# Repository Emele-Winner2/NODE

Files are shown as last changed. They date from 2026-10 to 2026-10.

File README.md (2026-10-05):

# NODE IO BOARD

The **NODE IO BOARD** is an embedded hardware node featuring an **ESP32-C3** microcontroller, onboard environmental and motion sensors, USB-C power/data delivery, and external micro-SD card storage. It serves as a compact, all-in-one sensor node designed for IoT applications, environmental monitoring, and motion tracking.

---

## Technical Specifications

### 1. Main Controller

* **MCU:** ESP32-C3-MINI-1 / ESP32-C3-MINI-2 module (RISC-V single-core processor).

* **Auto-Flash/Reset Circuitry:** Dual NPN transistor circuit (DTR/RTS) for automatic bootloader entry and flashing over USB.

* **Tactile Switches:** Dedicated `RESET` and `BOOT` push buttons.

### 2. Power Supply

* **Power Input:** USB Type-C Receptacle (USB 2.0 interface) or external 5V input header (`J2`).

* **ESD Protection:** Dedicated ESD protection diodes (`ESD9B5.0ST5G`) across VBUS, D+, and D- lines.

* **Voltage Regulation:** Onboard **LD1117S33TR** LDO regulator stepping down 5V (VBUS) to 3.3V for MCU and sensor power rails.

### 3. USB to UART Bridge

* **Bridge IC:** **CP2102N** (QFN-28) USB-to-UART bridge controller.

* Communicates directly with the ESP32-C3 via `U0RXD` and `U0TXD` pins.

### 4. Onboard Sensors & Peripherals

* **Environmental Sensor:** **BME688** gas, temperature, pressure, and humidity sensor connected over I²C (`SCL`, `SDA`).

* **Inertial Measurement Unit (IMU):** **BMI323** 6-axis IMU connected via I²C (`SCL`, `SDA`) with dedicated interrupt lines (`BMI_INT1`, `BMI_INT2`).

* **MicroSD Card Slot:** SPI-driven SD card slot (`MEM2067`) connected via SPI lines (`SPI_CLK`, `MOSI`, `MISO`, `SPI_CS`) for local data logging.

---

## Block Diagram Overview

```text
               +-----------------------+
               |  USB-C / 5V Header    |
               +-----------+-----------+
                           |
            +--------------+--------------+
            |                             |
    +-------v-------+             +-------v-------+
    | 3.3V LDO      |             | CP2102N USB-  |
    | (LD1117S33)   |             | to-UART Bridge|
    +-------+-------+             +-------+-------+
            |                             |
            +--------------+--------------+
                           |
                 +---------v---------+
                 |    ESP32-C3       |
                 |  Microcontroller  |
                 +----+----+----+----+
                      |    |    |
       +--------------+    |    +---------------+
       | I2C               | SPI                | Interrupts / Controls
+------v-------+    +------v-------+    +-------v------+
|   BME688     |    |  MicroSD     |    | Boot & Reset |
| Env Sensor   |    | Card Slot    |    |   Buttons    |
+--------------+    +--------------+    +--------------+
|   BMI323     |
|  6-Axis IMU  |
+--------------+

```

## Project Design Files

This hardware project was designed in **KiCad 10.0**:

* `NODE IO BOARD.kicad_sch` — Schematic source file

* Hardware revision: **Rev 1.0**

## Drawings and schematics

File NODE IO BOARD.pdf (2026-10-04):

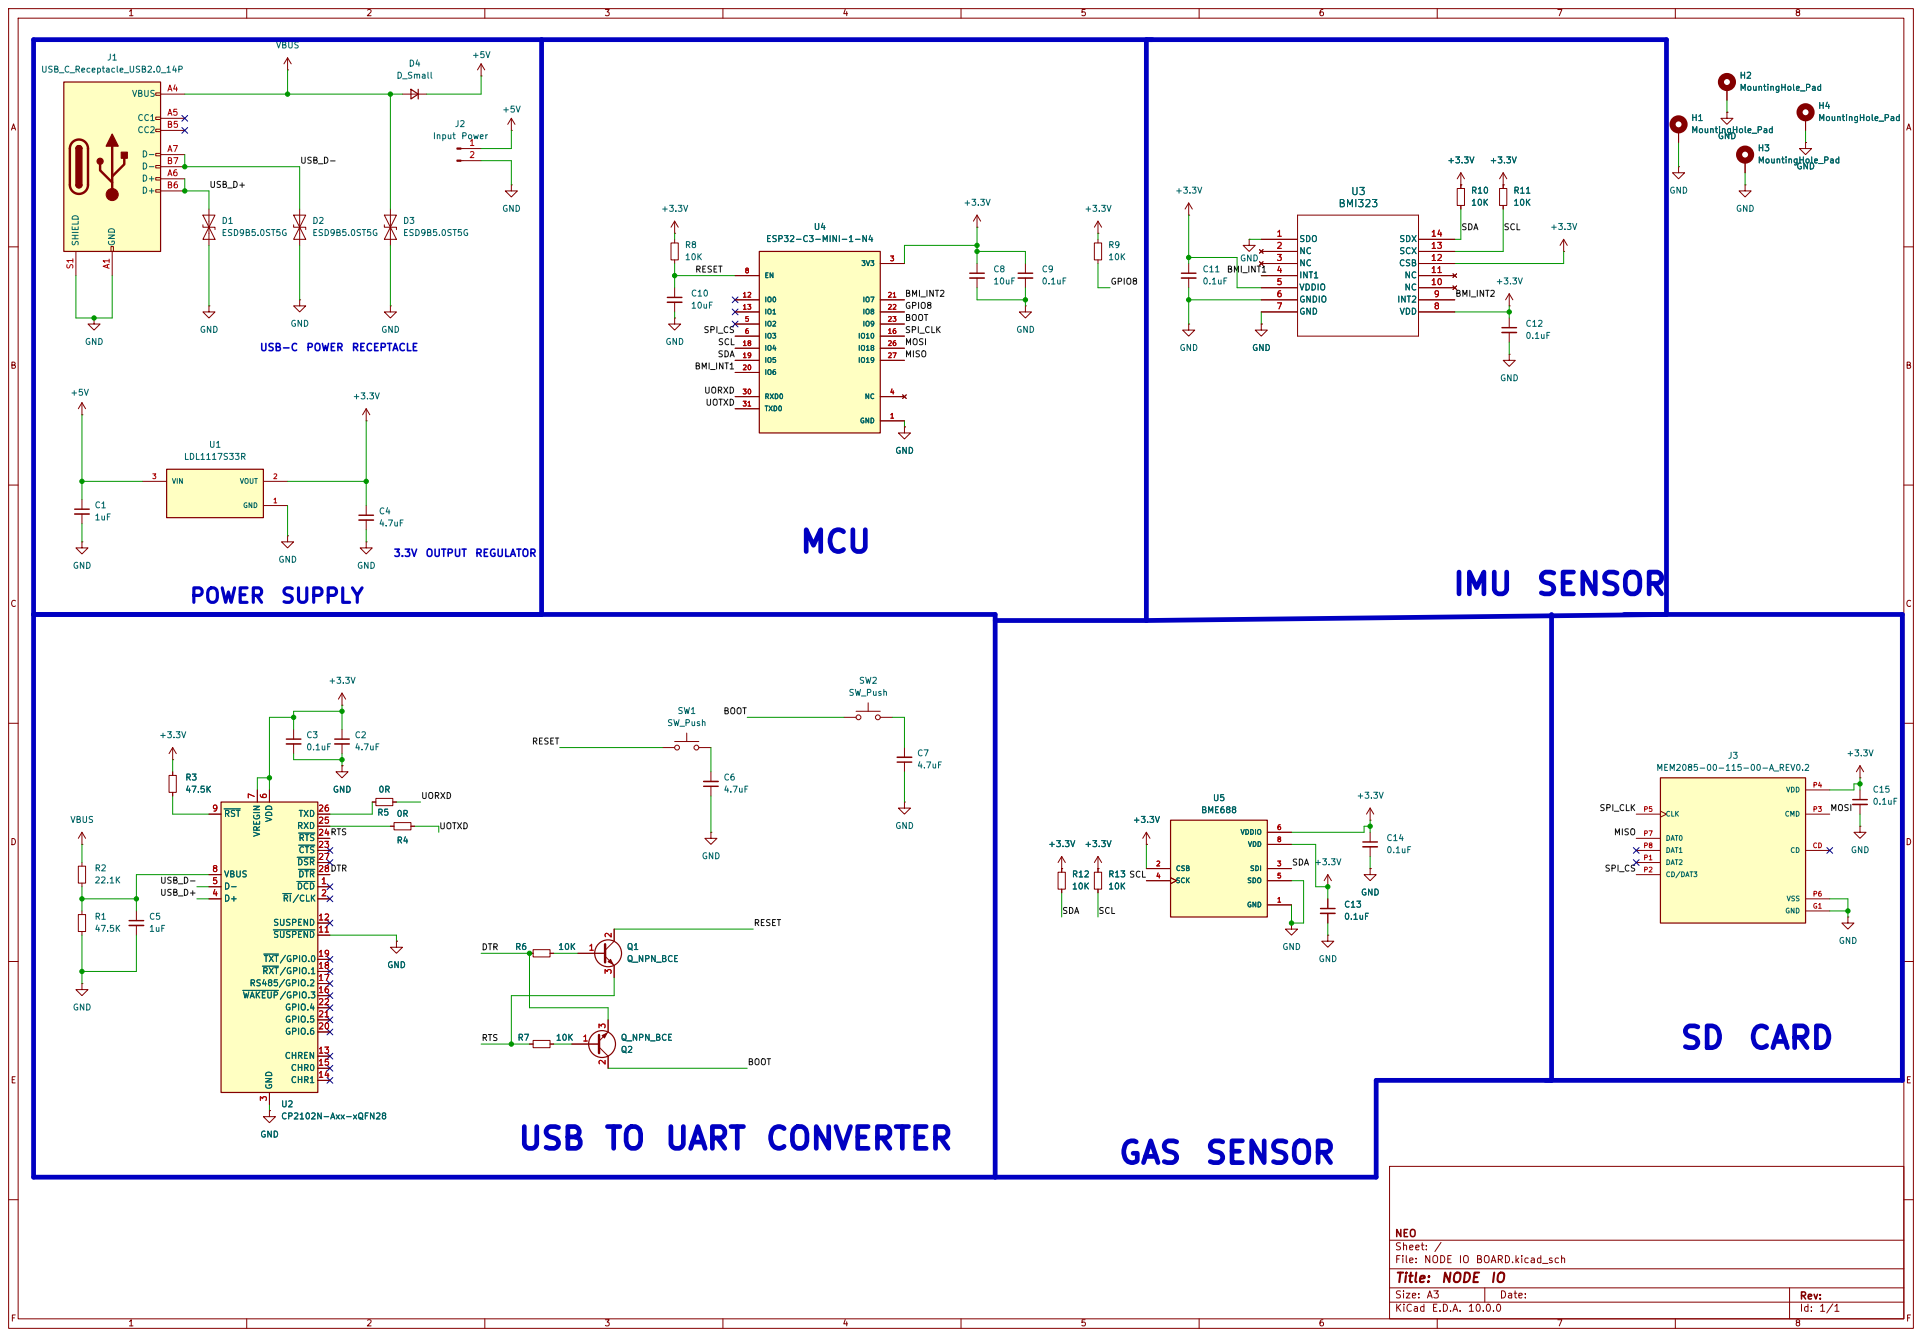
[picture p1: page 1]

USB TO UART CONVERTER

NEO
Sheet: /
File: NODE IO BOARD.kicad_sch
Title: NODE IO

Size: A3 | Rev: | F Date:
KiCad E.D.A. 10.0.0 | Id: 1/1

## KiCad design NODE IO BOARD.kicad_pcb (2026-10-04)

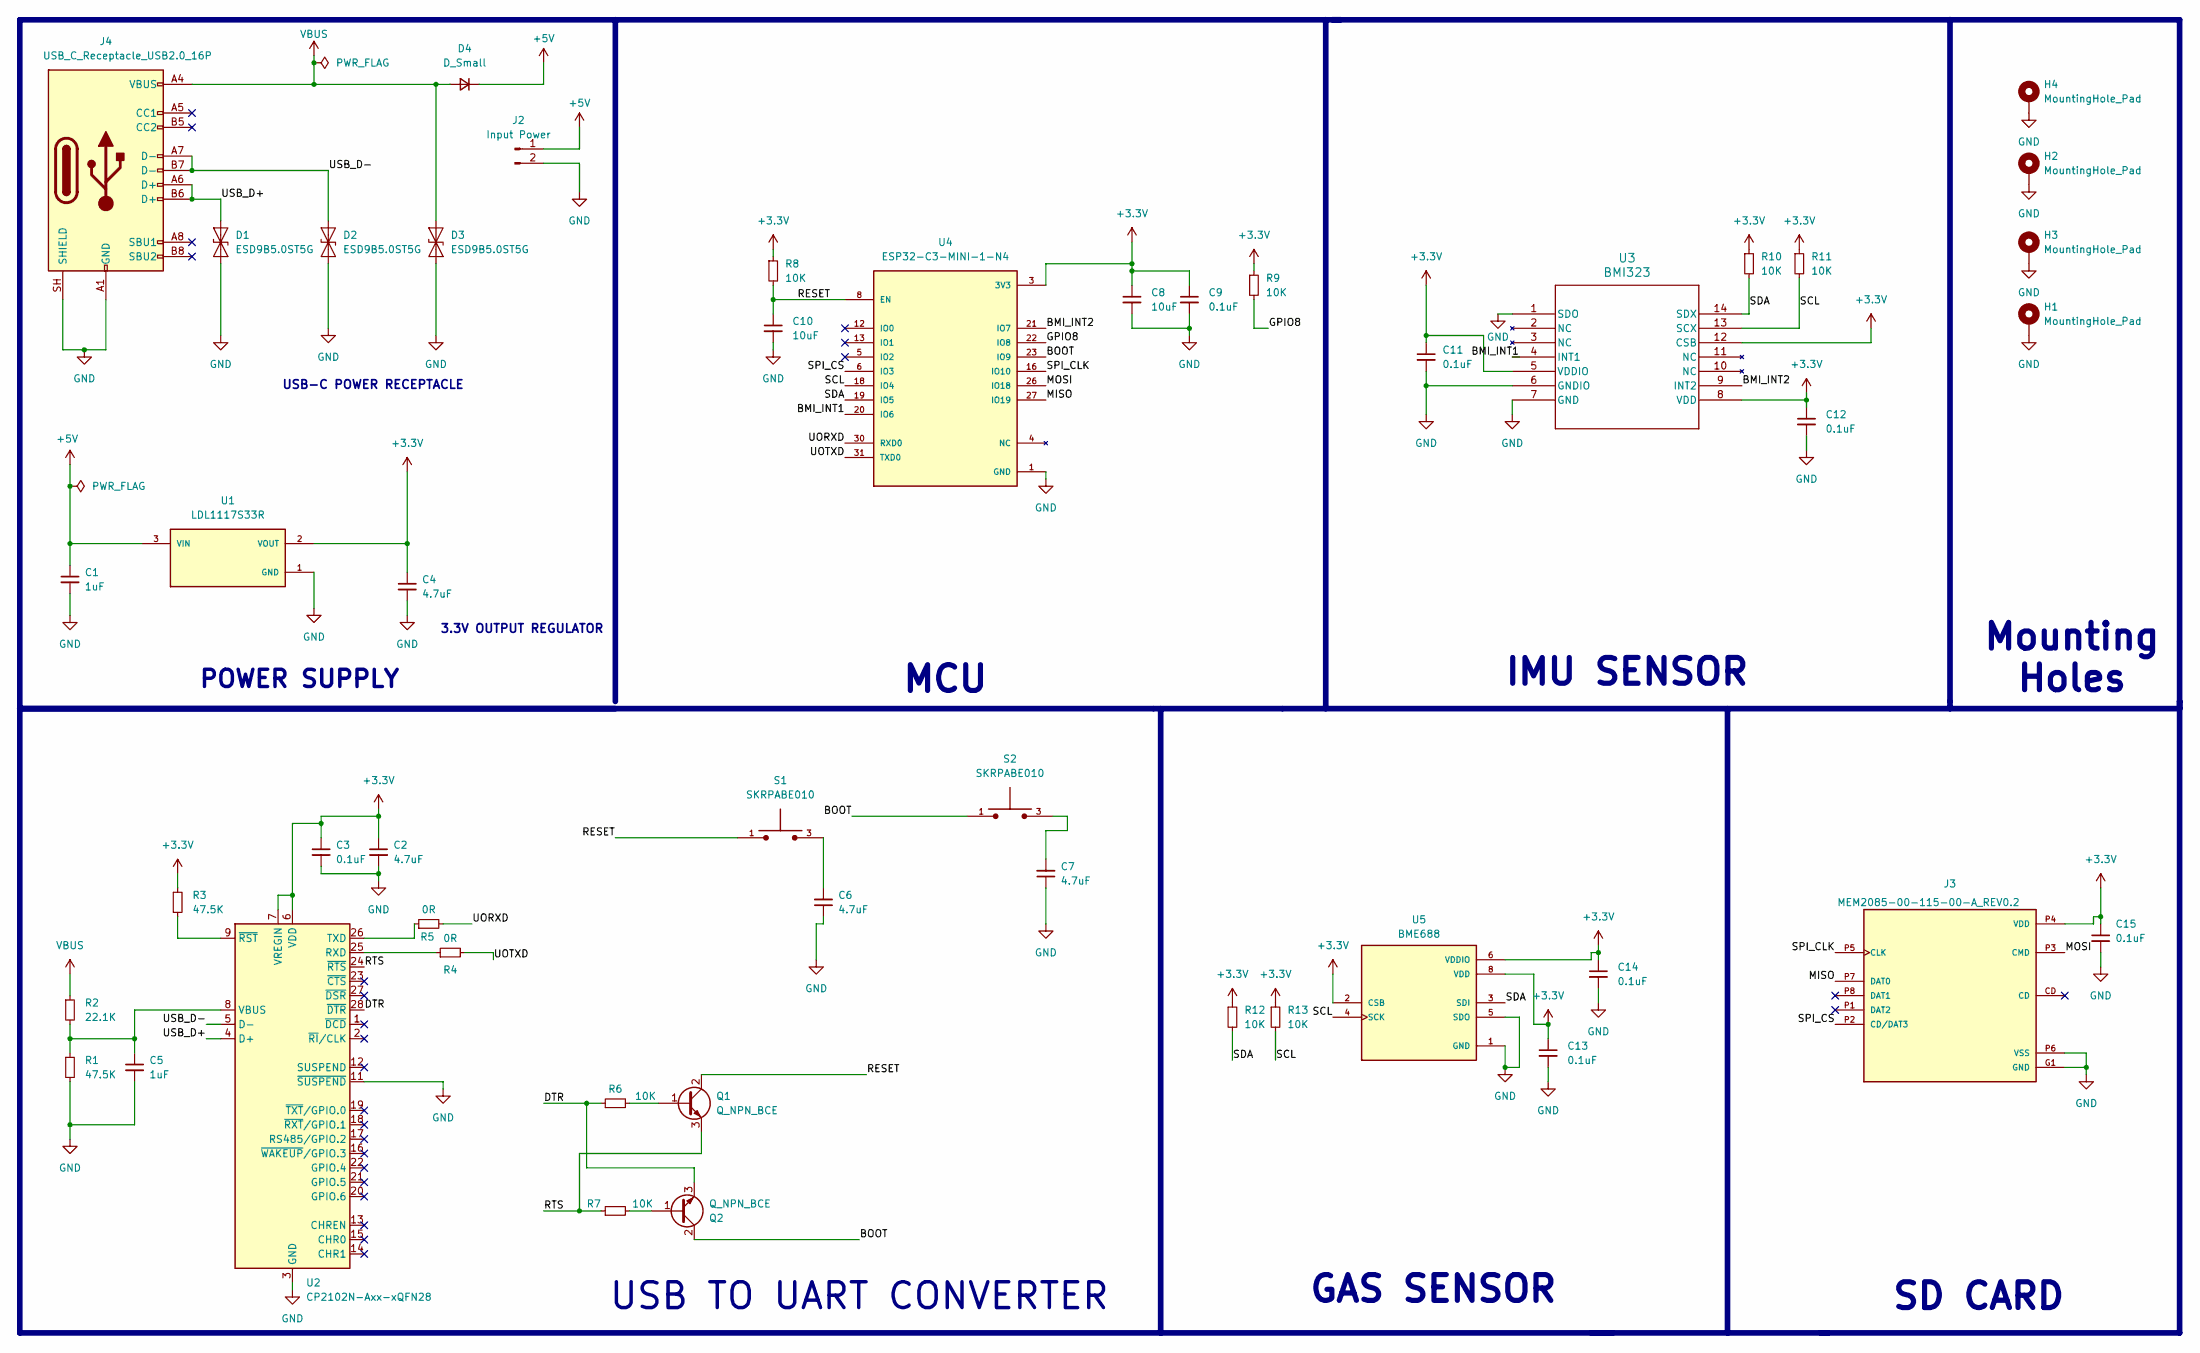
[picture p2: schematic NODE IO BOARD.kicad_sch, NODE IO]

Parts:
C1, C5: 1uF; C_0603_1608Metric
C2, C4, C6, C7: 4.7uF; C_0603_1608Metric
C3, C9, C11, C12, C13, C14, C15: 0.1uF; C_0603_1608Metric
C8, C10: 10uF; C_0603_1608Metric
D1, D2, D3: ESD9B5.0ST5G; D_SOD-923
D4: D_Small; D_SOD-123
H1, H2, H3, H4: MountingHole_Pad; MountingHole_2.5mm_Pad
J2: Input Power; JST_EH_S2B-EH_1x02_P2.50mm_Horizontal
J3: MEM2085-00-115-00-A_REV0.2; GCT_MEM2085-00-115-00-A_REV0.2; PARTREV 0.2
J4: USB_C_Receptacle_USB2.0_16P; USB_C_Receptacle_GCT_USB4105-xx-A_16P_TopMnt_Horizontal
Q1, Q2: Q_NPN_BCE; TSOT-23
R1, R3: 47.5K; R_0603_1608Metric
R2: 22.1K; R_0603_1608Metric
R4, R5: 0R; R_0603_1608Metric
R6, R7, R8, R9, R10, R11, R12, R13: 10K; R_0603_1608Metric
S1, S2: SKRPABE010; SW_SKRPABE010
U1: LDL1117S33R; SOT230P700X180-4N; PARTREV 7
U2: CP2102N-Axx-xQFN28; QFN50P500X500X100-29N
U3: BMI323; BMI323_BOS
U4: ESP32-C3-MINI-1-N4; XCVR_ESP32-C3-MINI-1-N4; PARTREV v1.0
U5: BME688; IC_BME688; PARTREV 1.0

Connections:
+3.3V: C2.1, C3.1, C4.1, C8.1, C9.1, C11.1, C12.1, C13.1, C14.1, C15.1, J3.P4 (VDD), R3.1, R8.1, R9.1, R10.1, R11.1, R12.1, R13.1, U1.2 (VOUT), U1.4 (VOUT), U2.6 (VDD), U2.7 (VREGIN), U3.5 (VDDIO), U3.8 (VDD), U3.12 (CSB), U4.3 (3V3), U5.2 (CSB), U5.6 (VDDIO), U5.8 (VDD)
+5V: C1.1, D4.1 (K), J2.1, U1.3 (VIN)
/BMI_INT1: U3.4 (INT1), U4.20 (IO6)
/BMI_INT2: U3.9 (INT2), U4.21 (IO7)
/BOOT: Q2.2 (C), S2.1, S2.2, U4.23 (IO9)
/DTR: Q2.3 (E), R6.1, U2.28 (~DTR)
/GPIO8: R9.2, U4.22 (IO8)
/MISO: J3.P7 (DAT0), U4.27 (IO19)
/MOSI: J3.P3 (CMD), U4.26 (IO18)
/RESET: C10.1, Q1.2 (C), R8.2, S1.1, S1.2, U4.8 (EN)
/RTS: Q1.3 (E), R7.1, U2.24 (~RTS)
/SCL: R11.2, R13.2, U3.13 (SCX), U4.18 (IO4), U5.4 (SCK)
/SDA: R10.2, R12.2, U3.14 (SDX), U4.19 (IO5), U5.3 (SDI)
/SPI_CLK: J3.P5 (CLK), U4.16 (IO10)
/SPI_CS: J3.P2 (CD/DAT3), U4.6 (IO3)
/UORXD: R5.2, U4.30 (RXD0)
/UOTXD: R4.2, U4.31 (TXD0)
/USB_D+: D1.2 (A2), J4.A6 (D+), J4.B6 (D+), U2.4 (D+)
/USB_D-: D2.2 (A2), J4.A7 (D-), J4.B7 (D-), U2.5 (D-)
GND: C1.2, C2.2, C3.2, C4.2, C5.2, C6.1, C7.1, C8.2, C9.2, C10.2, C11.2, C12.2, C13.2, C14.2, C15.2, D1.1 (A1), D2.1 (A1), D3.1 (A1), H1.1 (1_1), H2.1 (1_1), H3.1 (1_1), H4.1 (1_1), J2.2, J3.G1 (GND), J3.G2 (GND), J3.G3 (GND), J3.G4 (GND), J3.G5 (GND), J3.G6 (GND), J3.G7 (GND), J3.G8 (GND), J3.G9 (GND), J3.G10 (GND), J3.P6 (VSS), J4.A1 (GND), J4.A12 (GND), J4.B1 (GND), J4.B12 (GND), J4.SH (SHIELD), R1.2, U1.1 (GND), U2.3 (GND), U2.11 (~SUSPEND), U2.29 (GND), U3.1 (SDO), U3.6 (GNDIO), U3.7 (GND), U4.1 (GND), U4.2 (GND), U4.11 (GND), U4.14 (GND), U4.36 (GND), U4.37 (GND), U4.38 (GND), U4.39 (GND), U4.40 (GND), U4.41 (GND), U4.42 (GND), U4.43 (GND), U4.44 (GND), U4.45 (GND), U4.46 (GND), U4.47 (GND), U4.48 (GND), U4.49_1 (GND), U4.49_2 (GND), U4.49_3 (GND), U4.49_4 (GND), U4.49_5 (GND), U4.49_6 (GND), U4.49_7 (GND), U4.49_8 (GND), U4.49_9 (GND), U4.50 (GND), U4.51 (GND), U4.52 (GND), U4.53 (GND), U5.1 (GND), U5.5 (SDO), U5.7 (GND)
unnamed: C6.2, S1.3, S1.4
unnamed: C7.2, S2.3, S2.4
unnamed: Q1.1 (B), R6.2
unnamed: Q2.1 (B), R7.2
unnamed: R4.1, U2.25 (RXD)
unnamed: R5.1, U2.26 (TXD)
unnamed: C5.1, R1.1, R2.2, U2.8 (VBUS)
unnamed: R3.2, U2.9 (~RST)
VBUS: D3.2 (A2), D4.2 (A), J4.A4 (VBUS), J4.A9 (VBUS), J4.B4 (VBUS), J4.B9 (VBUS), R2.1

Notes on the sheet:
USB-C POWER RECEPTACLE
Mounting Holes
SD CARD
IMU SENSOR
MCU
GAS SENSOR
USB TO UART CONVERTER
3.3V OUTPUT REGULATOR
POWER SUPPLY

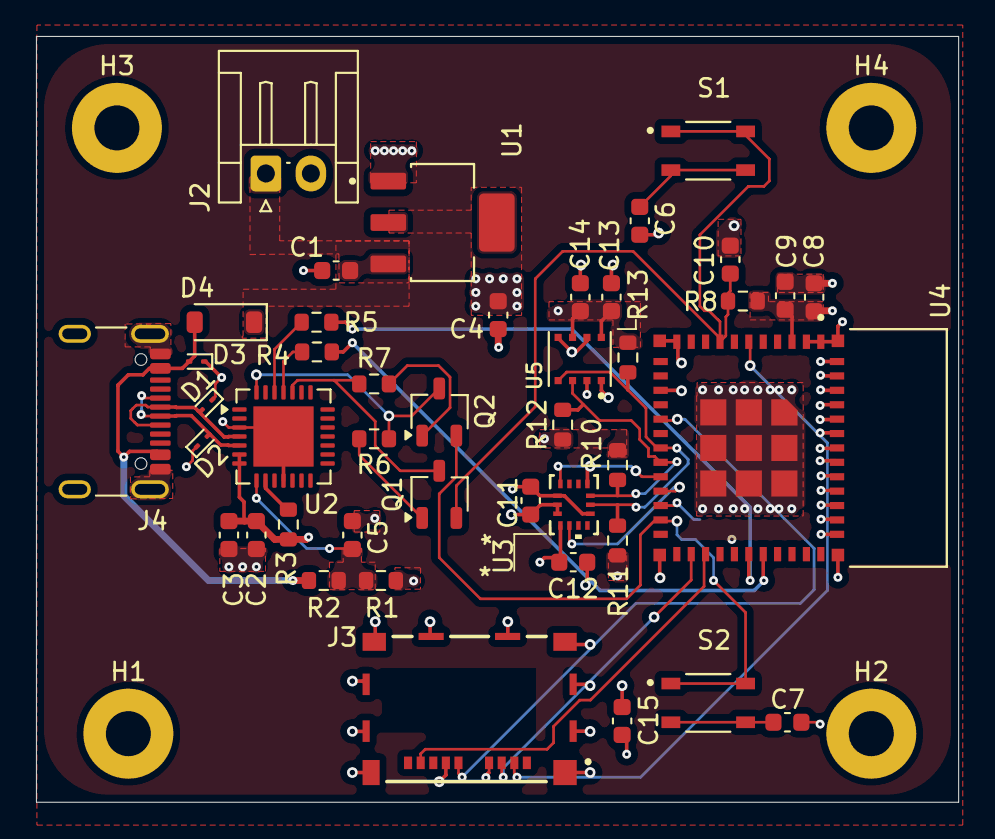
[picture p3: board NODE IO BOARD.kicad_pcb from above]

Board: 4 copper layers, 51.2 x 42.5 mm, 48 parts (1 on the bottom side), 29 nets.
